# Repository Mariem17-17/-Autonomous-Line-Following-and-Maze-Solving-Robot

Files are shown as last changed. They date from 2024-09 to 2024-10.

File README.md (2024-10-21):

# Autonomous Line-Following and Maze-Solving Robot

## Overview

This project is an Arduino-based autonomous robot designed to follow lines and solve mazes using a combination of infrared sensors, an MPU6050 accelerometer/gyroscope, ultrasonic sensors, and motor control. The robot uses Proportional-Integral-Derivative (PID) control to adjust its path and maintain smooth navigation while avoiding obstacles.

## Hardware Components

- **Arduino** (any compatible model)
- **MPU6050** (Accelerometer and Gyroscope)
- **Infrared Sensors** (IR for line detection)
- **Ultrasonic Sensor** (for obstacle detection)
- **DC Motors** (for movement)
- **LED** (for calibration indication)
- **Limit Switches** (for course control)
- **Power Supply and Wiring**

## Features

### 1. **Line Following**
The robot uses five infrared sensors to distinguish between black (line) and white (background) surfaces. During setup, these sensors are calibrated to detect threshold values for accurate line following.

### 2. **Maze Solving**
The robot utilizes a simple maze-solving algorithm, making decisions based on IR sensor data and ultrasonic sensor feedback to adjust its path through the maze.

### 3. **PID Control**
The MPU6050 provides accurate angle measurements, and a PID control system ensures the robot follows a straight path, even if it starts off misaligned.

### 4. **Obstacle Detection**
The ultrasonic sensor constantly measures distances to obstacles. When an object is detected too close, the robot adjusts its course or stops to avoid collisions.

## How It Works

1. **Sensor Calibration**: The robot calibrates its infrared sensors to differentiate between the black line and the white surface, storing the threshold values for optimal navigation.
  
2. **Line Following**: Using sensor data, the robot adjusts motor speeds to follow the line accurately. Different motor speeds ensure smooth turns and direction changes.

3. **Maze Navigation**: Upon entering a maze, the robot switches modes and begins solving the maze using its sensors to make decisions at each turn or intersection.

4. **Obstacle Avoidance**: The ultrasonic sensor ensures the robot avoids obstacles by measuring the distance to any objects in its path, prompting it to stop or reroute.

## Code Breakdown

- **Infrared Sensors**: Used to calibrate and detect line positions.
- **Motors**: Control the movement and turning of the robot.
- **Ultrasonic Sensor**: Used for obstacle detection and avoidance.
- **PID Control**: Maintains the robot’s direction and speed using data from the MPU6050.
- **Limit Switches**: Detect when the robot reaches the end of the course or a boundary.

## Setup Instructions

1. **Install Required Libraries**:
   - Ensure you have the `Wire.h` and `MPU6050_light.h` libraries installed in your Arduino IDE.
  
2. **Wiring**:
   - Connect the motors, IR sensors, MPU6050, and ultrasonic sensors as per the wiring diagram in the code. Ensure all components have proper power connections.
   
3. **Upload the Code**:
   - Upload the provided Arduino code to the robot.

## Calibration Process

1. Turn on the robot, which will enter the calibration phase with an LED indicator.
2. The robot will automatically calibrate the infrared sensors by scanning the black and white surfaces.
3. After calibration, the robot will begin line-following mode and can be placed on the track or maze.

## PID Tuning

The PID control constant `kp` can be adjusted to improve movement performance. A higher value results in quicker responses to misalignment, while a lower value produces smoother but slower corrections.

## Key Functions

- **seuilblack()** and **seuilwhite()**: Calculate the threshold values for black and white surfaces using the IR sensors.
- **forward_maze()**, **right_turn()**, **left_turn()**: Control robot movement while navigating the maze.
- **dour_pid()**: Adjusts the robot’s heading based on current angle readings from the MPU6050.
- **maze()**: The main maze-solving logic, adjusting movement based on sensor data.

## Usage

Once powered on, place the robot on a track or maze. The robot will autonomously follow the line, and upon detecting a maze, it will switch to maze-solving mode. The ultrasonic sensor ensures obstacle avoidance.

## Future Improvements

- **Dynamic Speed Optimization**: Adjusting speed based on track complexity.
- **Enhanced Maze Solving**: Implementing more advanced algorithms for complex mazes.
- **Improved Obstacle Avoidance**: Developing a more robust system for collision avoidance.

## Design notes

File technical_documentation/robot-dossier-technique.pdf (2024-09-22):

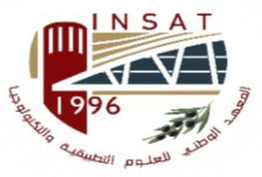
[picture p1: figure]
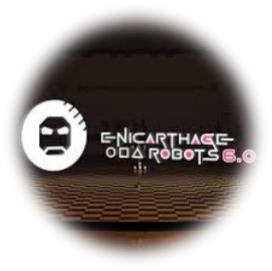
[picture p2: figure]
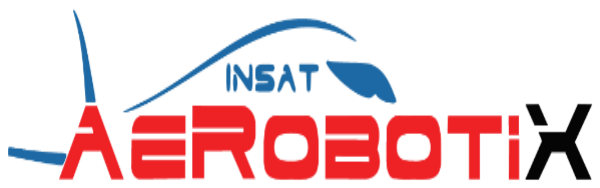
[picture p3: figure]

DOSSIER TECHNIQUE DU ROBOT

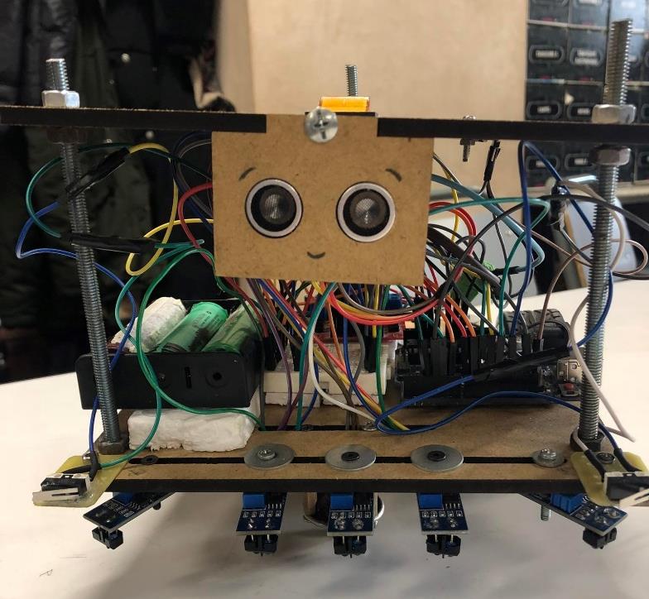
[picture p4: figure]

Réalisé Par :

-Ben Mehrez Mariem

-Guedidi Melek

-Hammami Nada

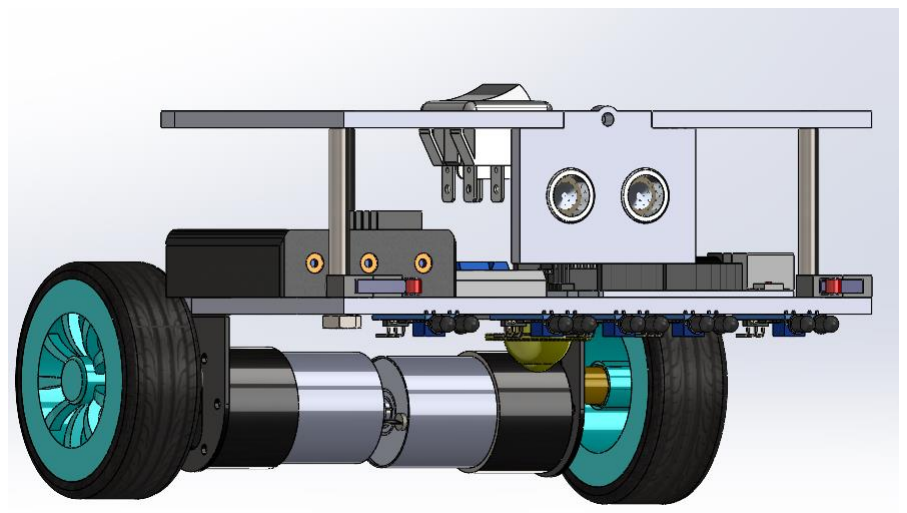
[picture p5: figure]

## Sommaire :

I. Présentation du club
II. | Présentation du robot
| a)Principe de fonctionnement
b) Conception mécanique
| c)Conception Electronique
d) Matériels
e) Conception d’une carte de puissance :

### I. Présentation du Club :

Notre club est leader dans le domaine de la robotique et de l’aéronautique en Tunisie, et représente le pole robotique et aéronautique de l’INSAT. AEROBOTIX est une famille renfermant plus de 150 membres. Nous cherchons à rendre chaque rencontre enrichissante d’un point de vue humain et technologique .Chaque membre apporte de l’énergie aux autres, nous nous attachons à insuffler cette énergie pour innover et concrétiser nos projets qui feront objets des compétitions et des expositions nationales et internationales. Nous offrons une excellente formation pour nos membres et nous garantissons une expérience innovante, exceptionnelle et collaborative. Notre club est le club le plus performant à l’INSAT avec plus de 100 participations à des compétitions nationales, 17 participations à l’échelle internationale et remportant ainsi plusieurs prix, plus que 35 médailles et 25 trophées.

### II. Présentation du robot :

a) Principe du fonctionnement :

Dans ce jeu, les robots tentent de suivre et survivre aux rebondissements physiques des jeux SQUID GAME. Le compétiteur doit suivre le bon chemin, schématisé sur la maquette par le mot [SQUID GAME]. Il est appelé à résoudre le maze du lettre M ainsi que continuer son chemin sur la partie de maquette de couleurs inversées et célébrer sa victoire.

b) Conception mécanique :

Il s’agit d’un assemblage virtuel des principales pièces de notre robot. Cette conception 3D nous permettra de :

| • Assurer les bonnes dimensions de totalité des pièces.

- Imprimer sur papier les dimensions réelles des pièces une par une, ce qui va nous faciliter leur fabrication.
- Avoir une idée virtuelle de notre projet.

Et pour cette raison qu’on a utilisé le logiciel de conception
3D « SOLIDWOKS »

✓ ASSEMBLAGE DU ROBOT
- Vue de face :

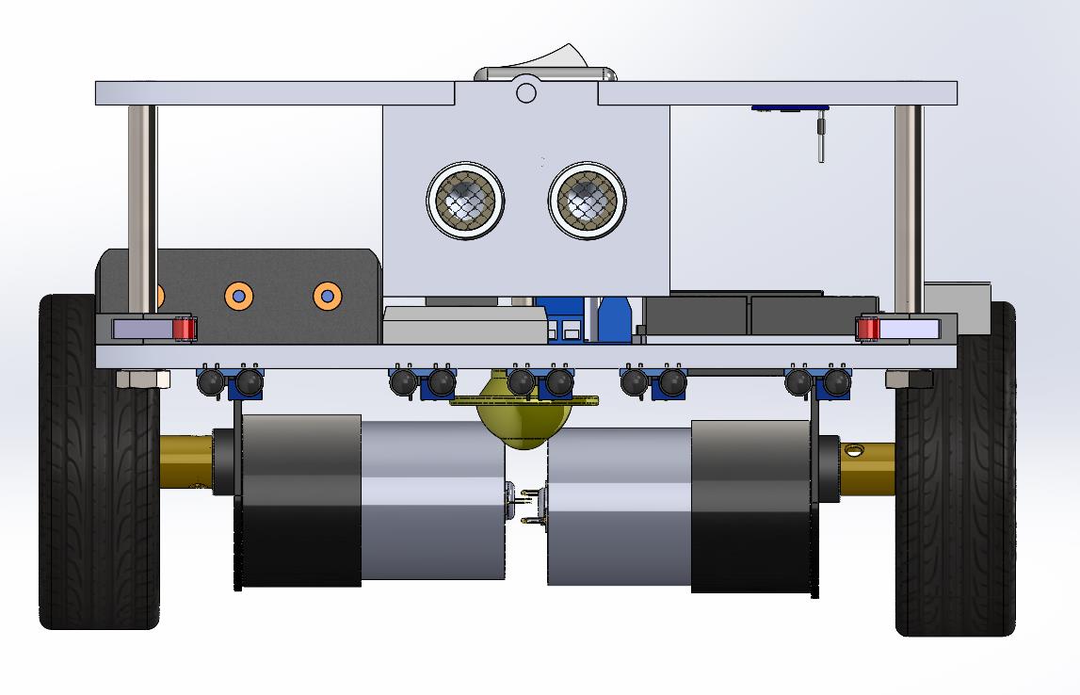
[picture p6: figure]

- Vue de Dessous :

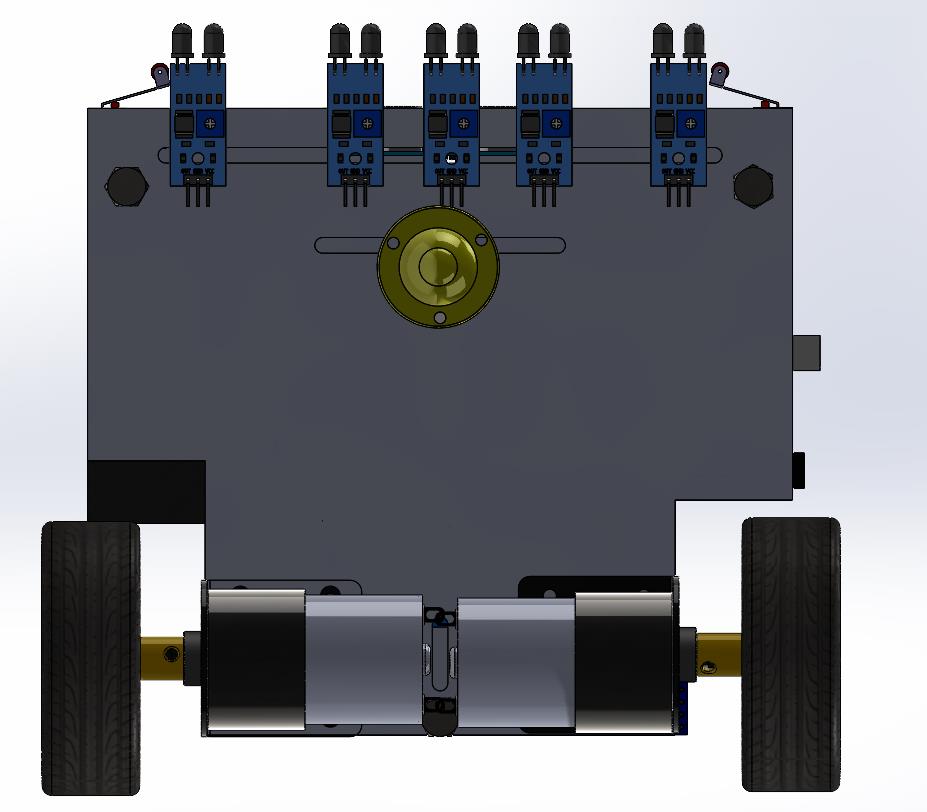
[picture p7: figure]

- Vue de Dessus :

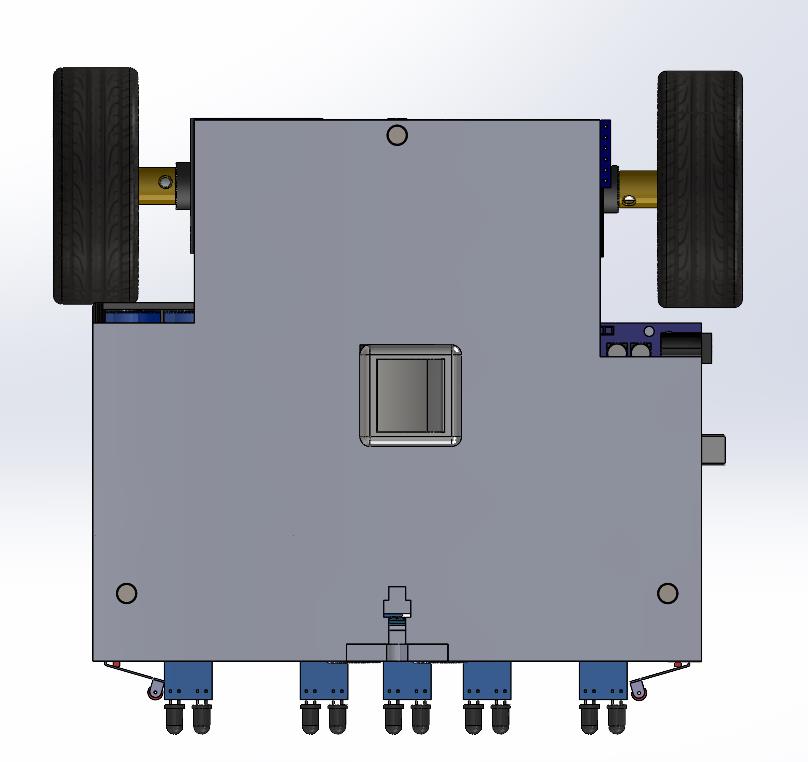
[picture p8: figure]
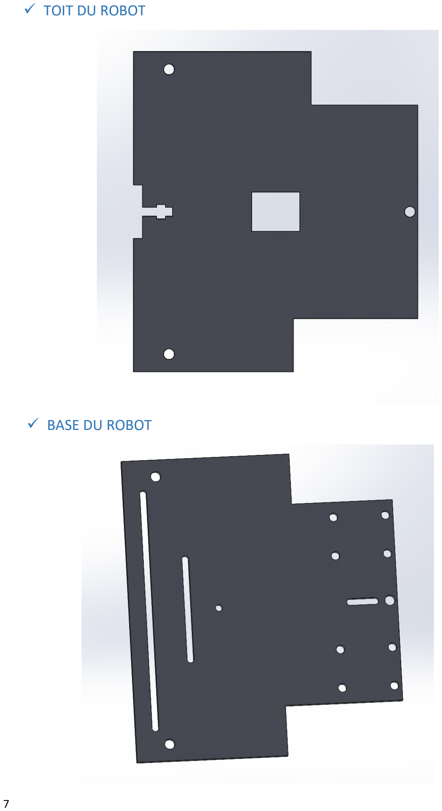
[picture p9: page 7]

✓ TOIT DU ROBOT

✓ BASE DU ROBOT

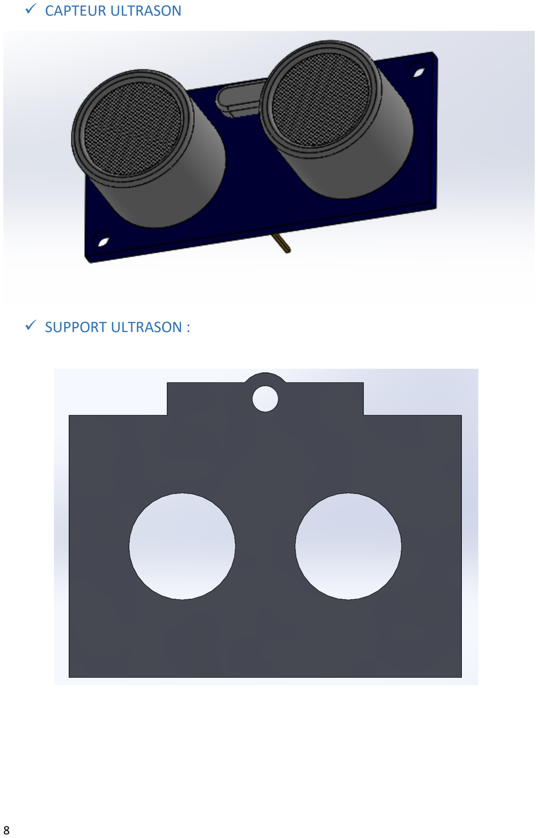
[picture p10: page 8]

✓ CAPTEUR ULTRASON

✓ SUPPORT ULTRASON :

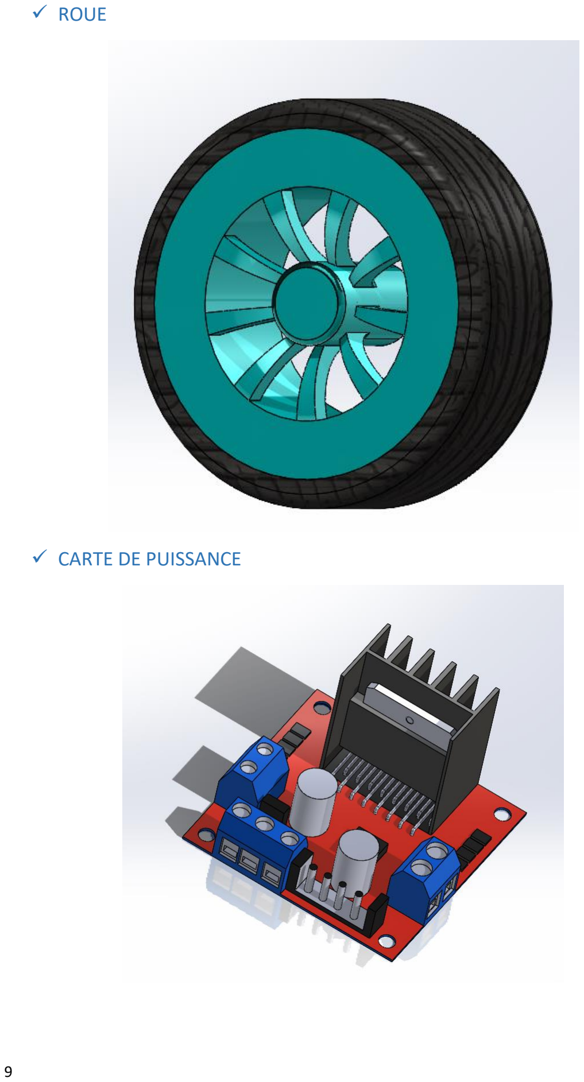
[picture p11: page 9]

✓ ROUE

✓ CARTE DE PUISSANCE

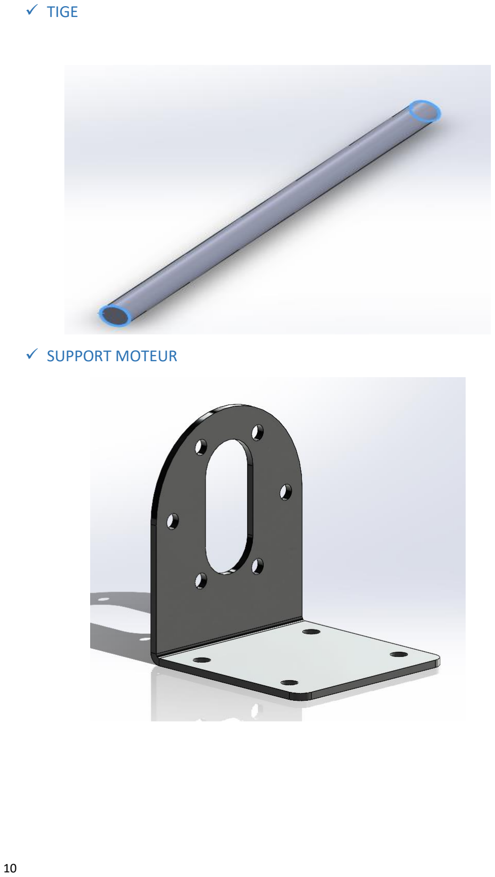
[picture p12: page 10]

✓ TIGE

✓ SUPPORT MOTEUR

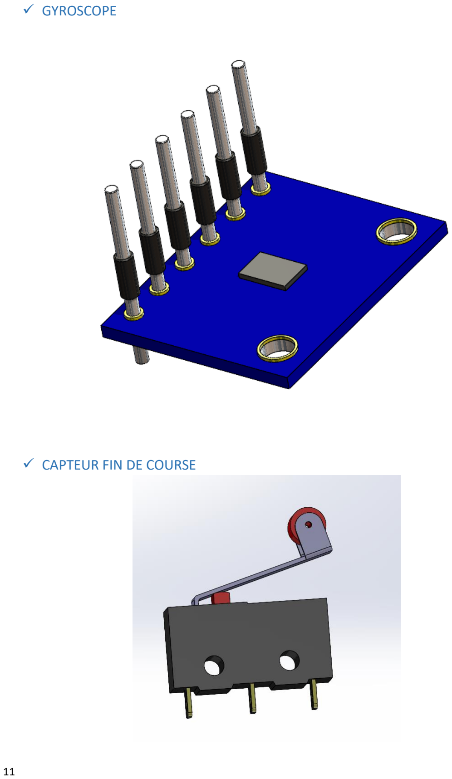
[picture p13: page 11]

✓ GYROSCOPE

✓ CAPTEUR FIN DE COURSE

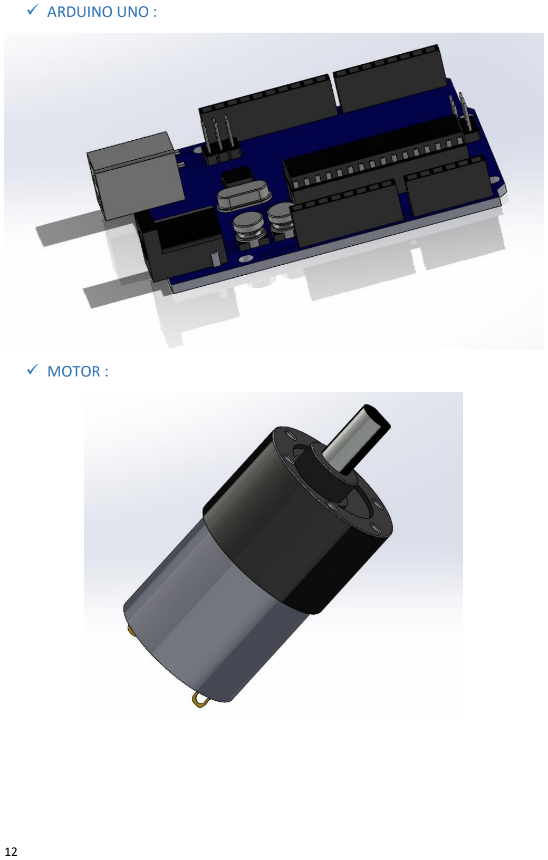
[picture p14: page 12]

✓ ARDUINO UNO :

✓ MOTOR :

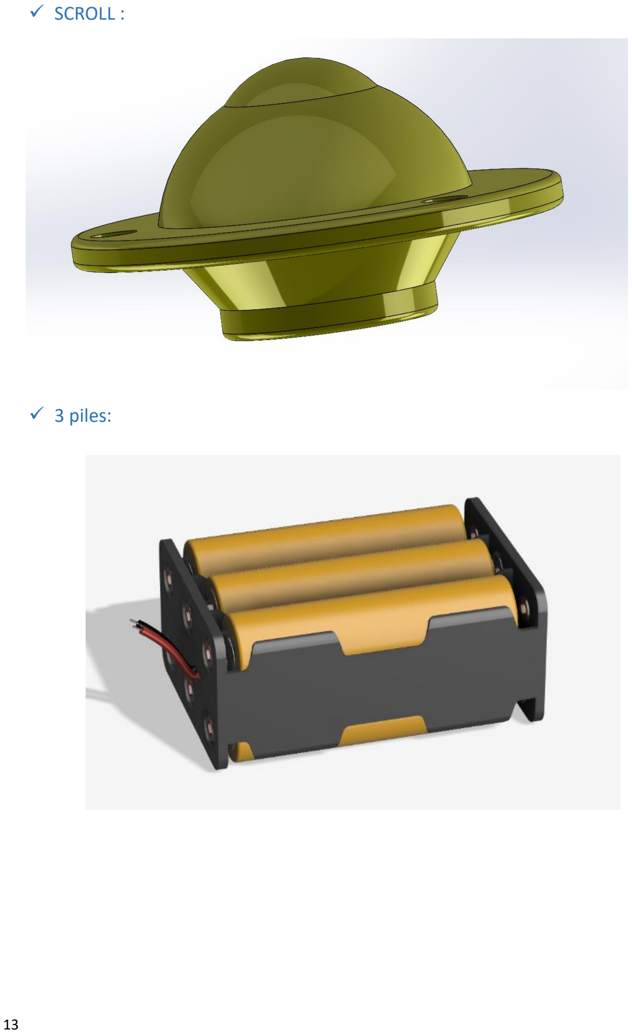
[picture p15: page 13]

✓ SCROLL :

✓ 3 piles:

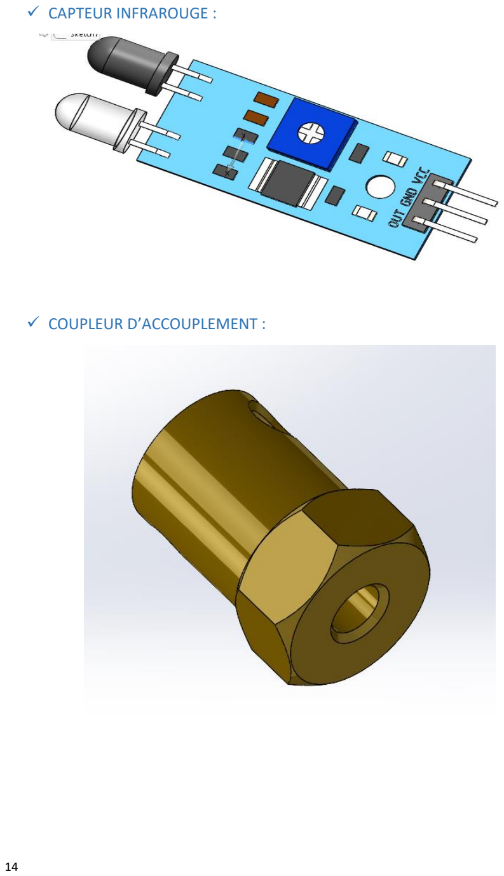
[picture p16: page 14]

✓ CAPTEUR INFRAROUGE :

✓ COUPLEUR D’ACCOUPLEMENT :

c) Conception électronique :

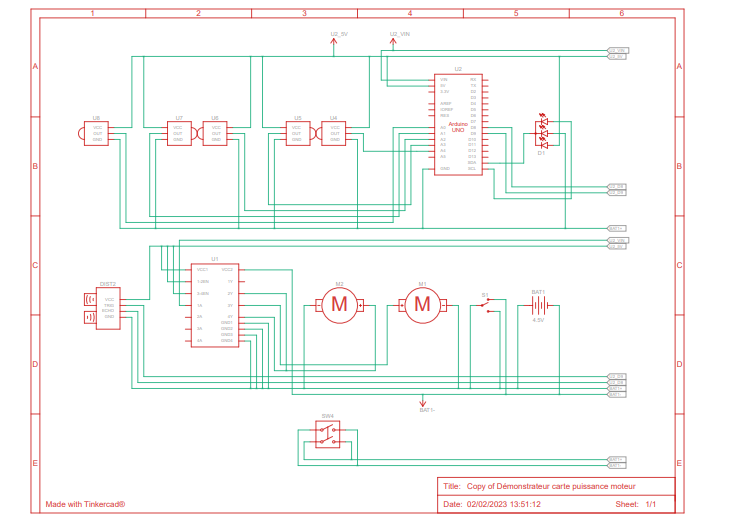
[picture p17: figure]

d) Matériels :
Quantité | Désignation
Partie Mécanique | 2 | Moteur
| 2 | Roue
| 1 | Scroller
| 1 | Bouton Marche/arrêt
| 2 | Coupleur d’accouplement
| 3 | Pile
Partie Electronique | 1 | Carte puissance
| 5 | Capteur Infrarouge
| 1 | Capteur Ultrason
| 1 | Gyroscope
| 2 | Capteur fin de course
Partie Programmation | 1 | Microcontrôleur (ARDUINO UNO)
e) Conception d’une carte de puissance :

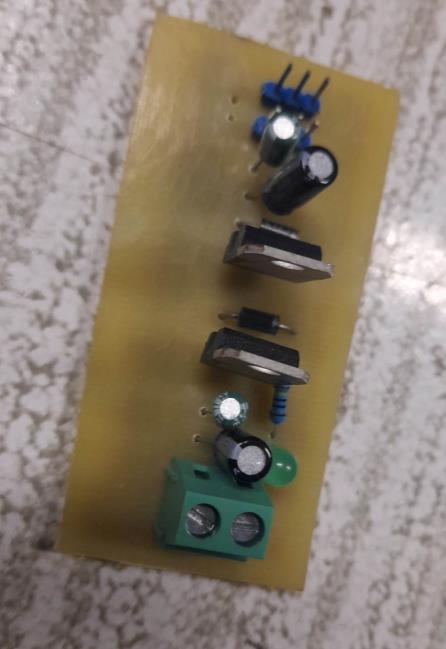
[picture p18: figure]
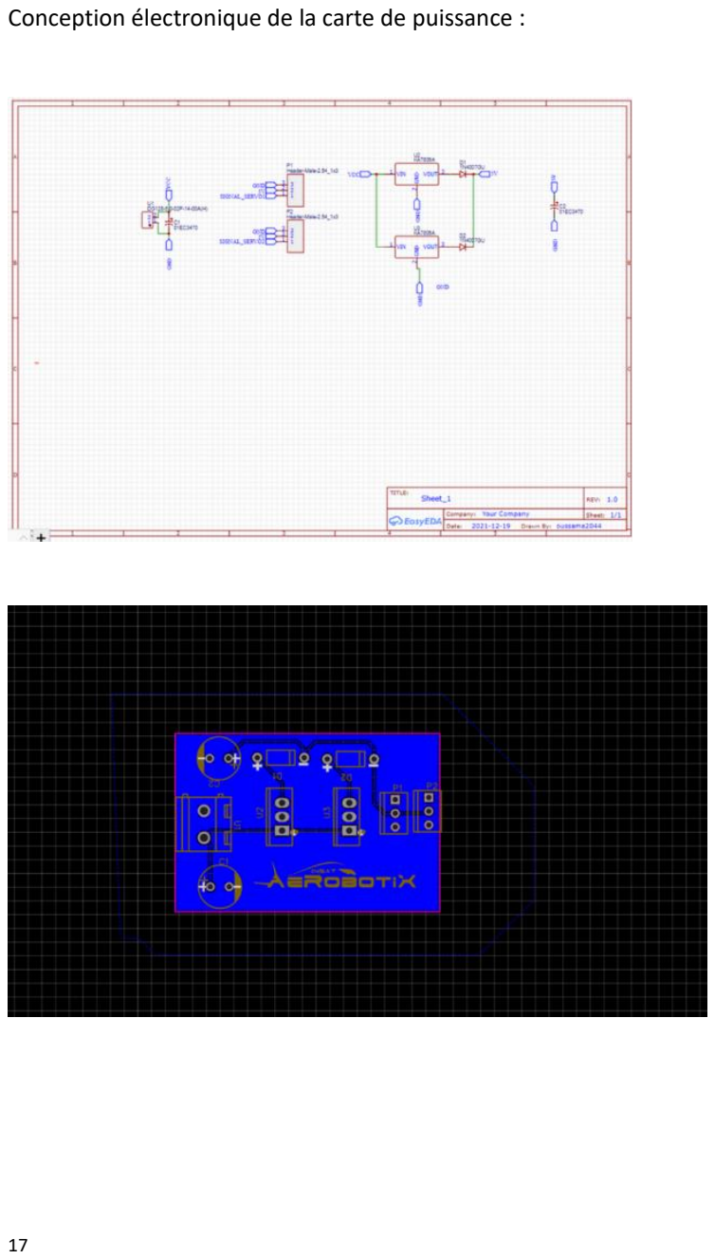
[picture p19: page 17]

Conception électronique de la carte de puissance :

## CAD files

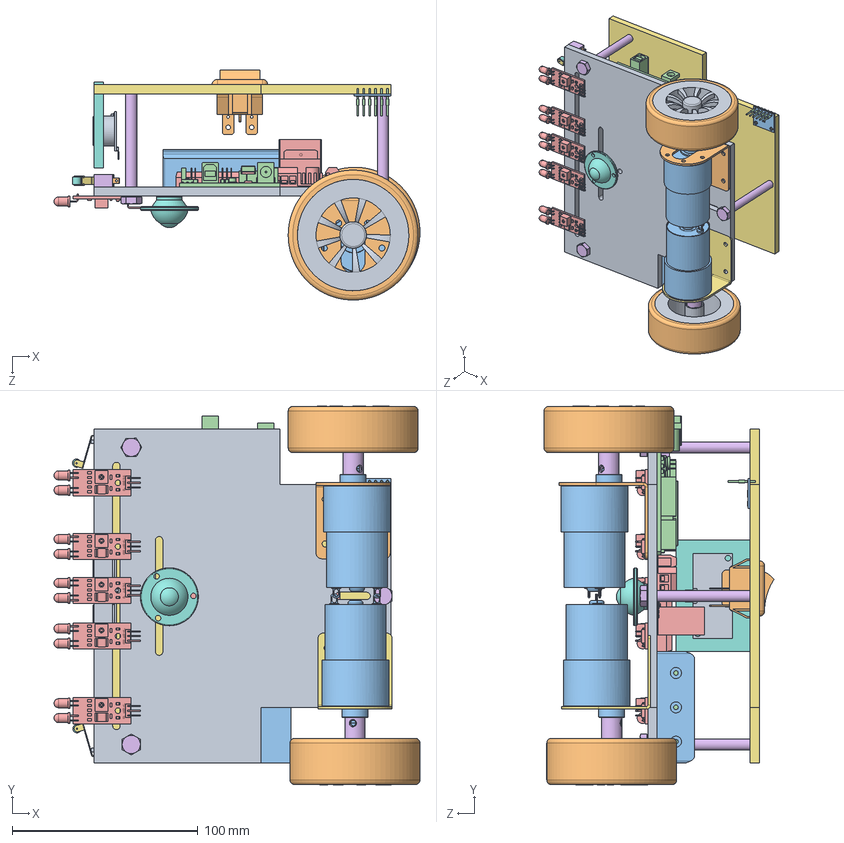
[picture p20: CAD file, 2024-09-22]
mechanical_design/final_assembly.SLDASM
197.1 x 204.0 x 123.9 mm
GDOURAbas
37 mm DC Geared Motor Mounting Bracket
motor x 2
Arduino Uno R3
Motor Driver
6mmID_18mmL_hex_adapter.stp x 2
37 mm DC Geared Motor Mounting Bracket (1)
scroll
wheel2 x 2
contour-wheel x 2
pin
battery_base x 3
Electronics_Prototyping_Breadboard_35x45x8_17x10holes
hexagon head bolts-full thread gb x 3
GDOURAhaut
TEST1SUPPORT
HC-SR04 Ultrasonic sensor
Switch JS618.stp
Gyroscope sensor
Gyroscope sensor straight lead x 6
Sensor, IR, Arduino Type, Flying Fish MH-B x 5
corp x 2
support Roulette x 2
Roulette x 2
Poussoir x 2
Patte x 6

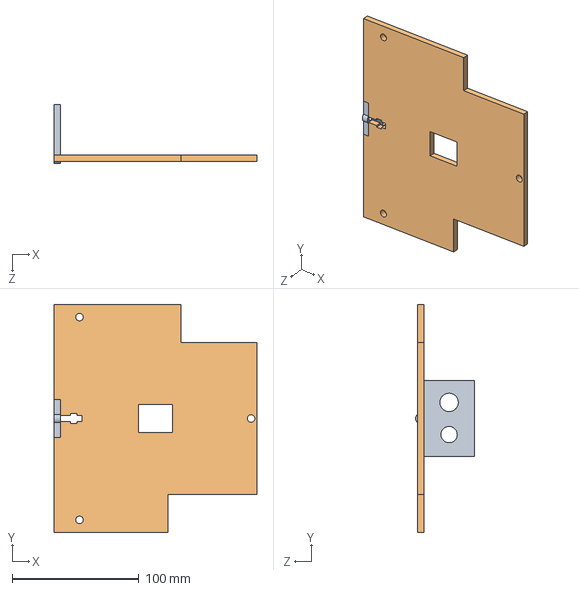
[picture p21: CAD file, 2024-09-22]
mechanical_design/Baseh_supp.SLDASM
160.0 x 180.0 x 46.5 mm
TEST1SUPPORT
GDOURAhaut

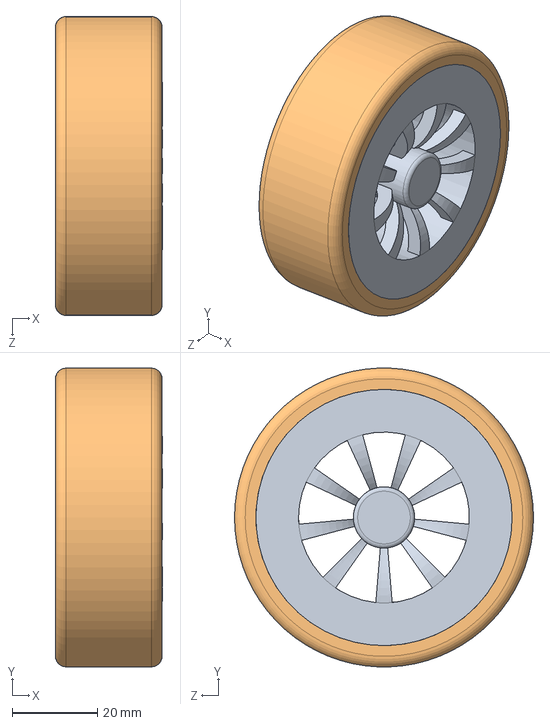
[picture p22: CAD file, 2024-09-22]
mechanical_design/AssemblageWheel.SLDASM
25.1 x 69.9 x 70.0 mm
wheel2
contour-wheel

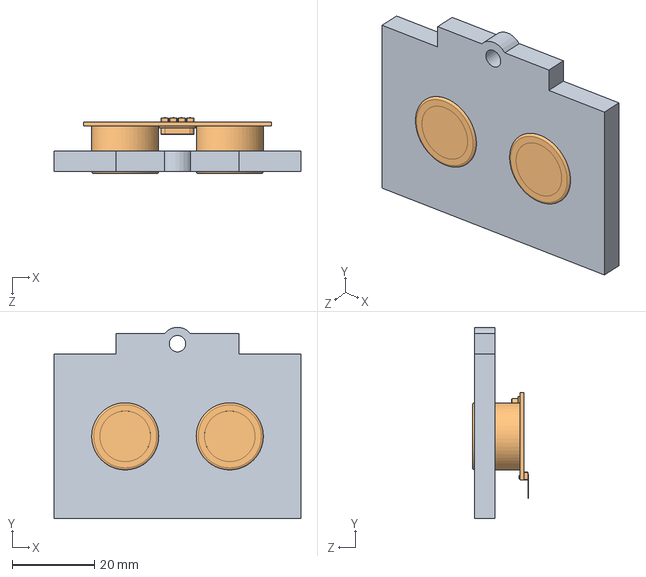
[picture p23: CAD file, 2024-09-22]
mechanical_design/AssemblageUltraSon.SLDASM
60.0 x 46.5 x 13.6 mm
TEST1SUPPORT
HC-SR04 Ultrasonic sensor

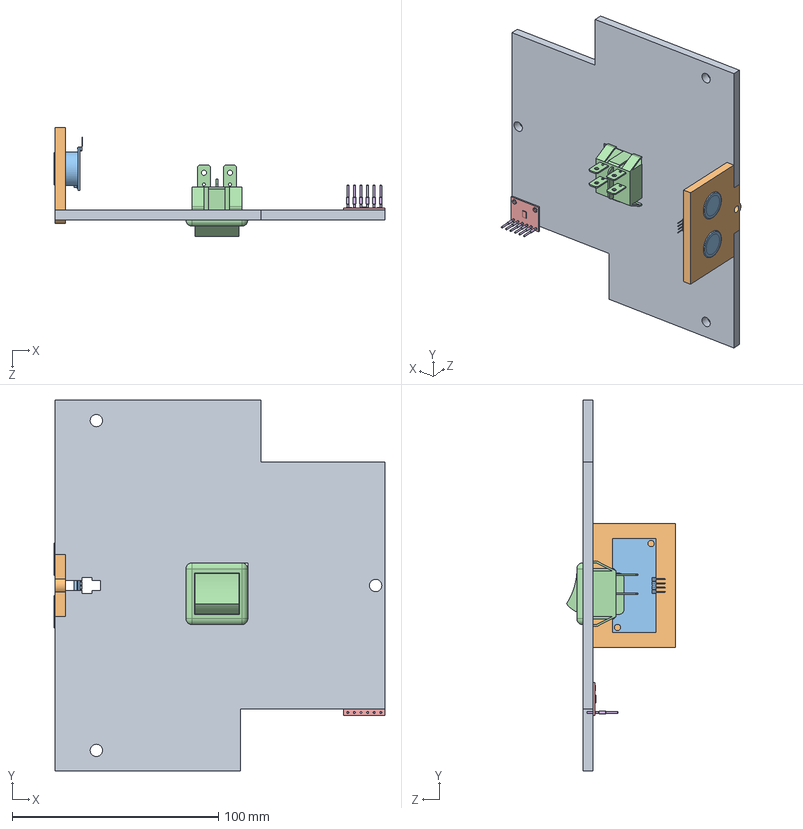
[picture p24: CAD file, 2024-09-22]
mechanical_design/AssemblageBaseHaute.SLDASM
160.5 x 180.0 x 52.9 mm
GDOURAhaut
TEST1SUPPORT
HC-SR04 Ultrasonic sensor
Switch JS618.stp
Gyroscope sensor
Gyroscope sensor straight lead x 6

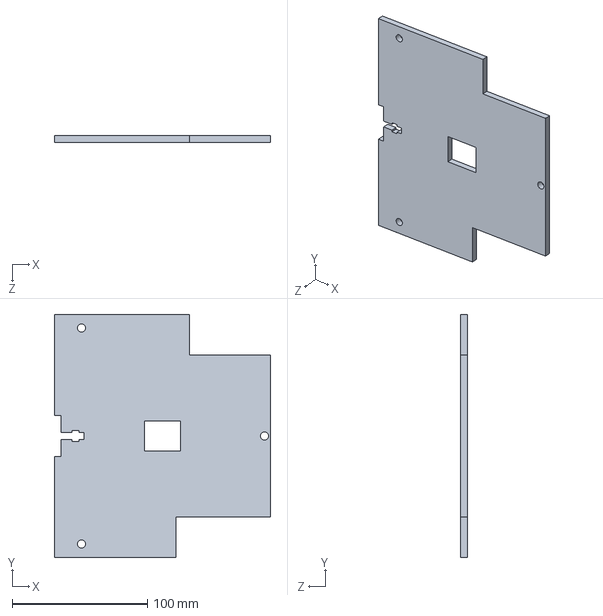
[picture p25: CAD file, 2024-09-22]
mechanical_design/Assemblage2.SLDASM
160.0 x 180.0 x 5.00 mm

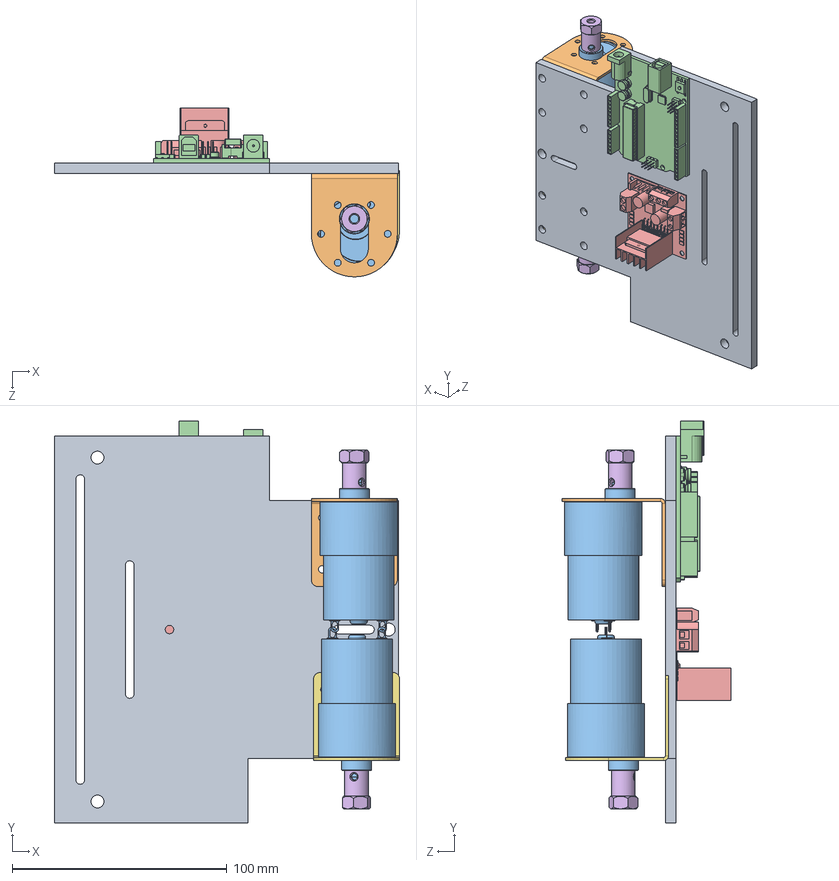
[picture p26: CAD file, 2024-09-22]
mechanical_design/Assemblage1-2.SLDASM
160.5 x 187.0 x 78.5 mm
GDOURAbas
37 mm DC Geared Motor Mounting Bracket
motor x 2
Arduino Uno R3
Motor Driver
6mmID_18mmL_hex_adapter.stp x 2
37 mm DC Geared Motor Mounting Bracket (1)

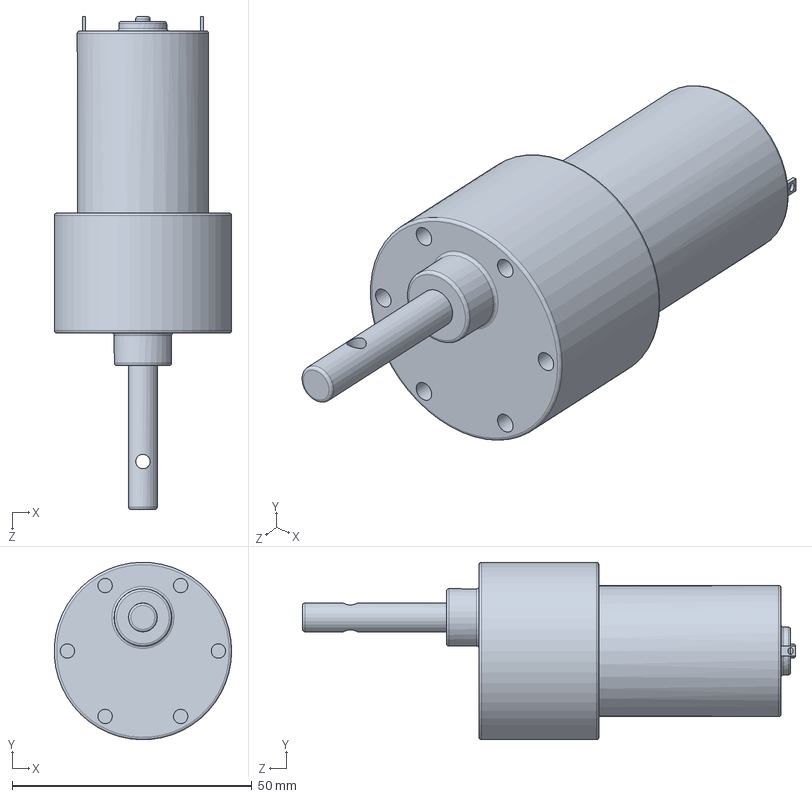
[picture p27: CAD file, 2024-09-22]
mechanical_design/moteur + réducteur.SLDPRT
37.0 x 37.0 x 102.8 mm

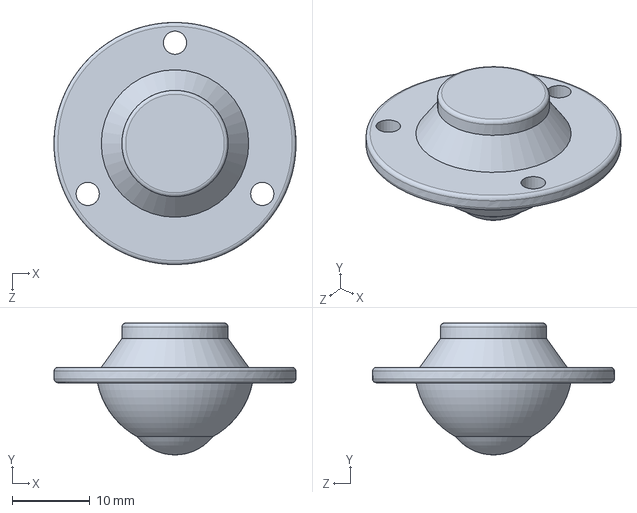
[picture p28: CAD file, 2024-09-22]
mechanical_design/scroll.SLDPRT
31.2 x 17.0 x 31.2 mm

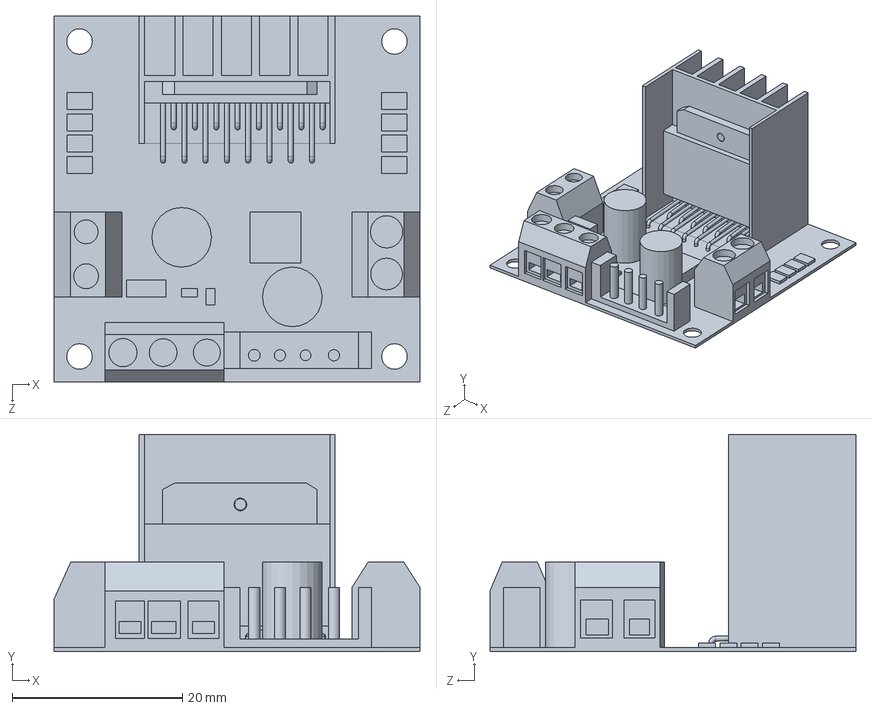
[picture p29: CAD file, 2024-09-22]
mechanical_design/Motor Driver.SLDPRT
43.0 x 25.5 x 43.0 mm

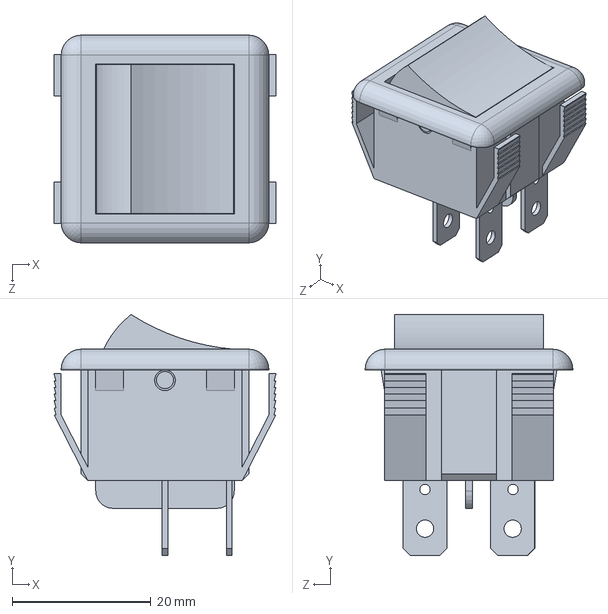
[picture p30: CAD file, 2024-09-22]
mechanical_design/Switch JS618.stp.SLDPRT
32.0 x 34.8 x 30.0 mm

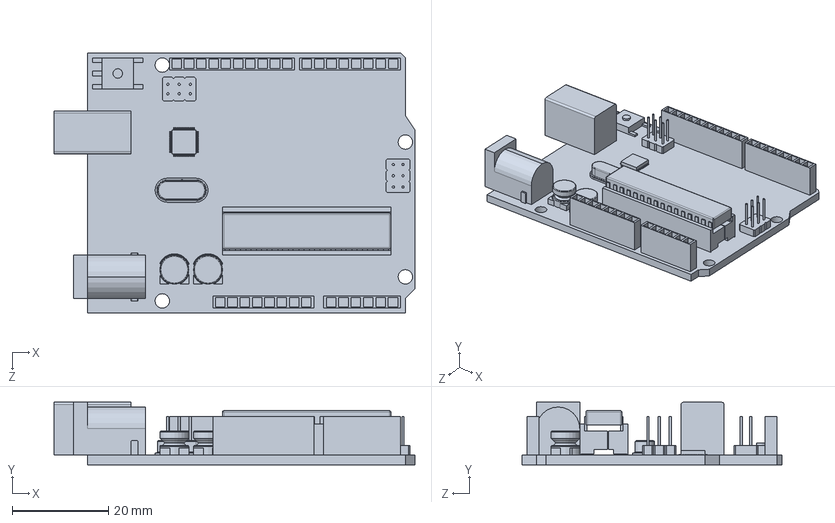
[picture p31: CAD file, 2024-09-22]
mechanical_design/Arduino Uno R3.SLDPRT
75.0 x 13.0 x 54.0 mm

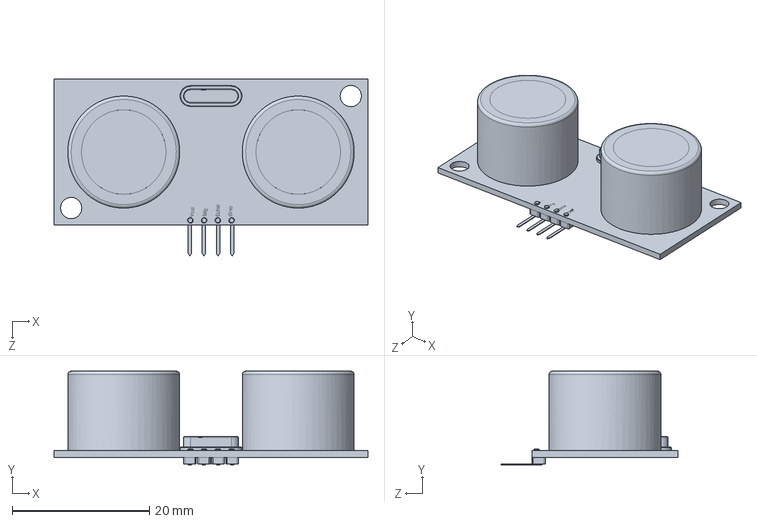
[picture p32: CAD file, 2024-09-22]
mechanical_design/HC-SR04 Ultrasonic sensor.SLDPRT
45.7 x 13.6 x 25.8 mm

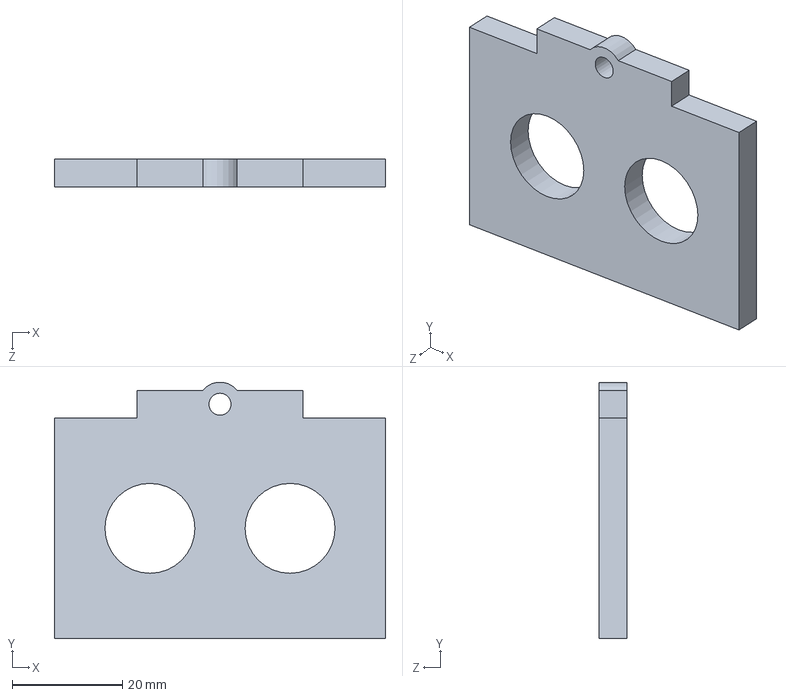
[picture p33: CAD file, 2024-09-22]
mechanical_design/TEST1SUPPORT.SLDPRT
60.0 x 46.5 x 5.00 mm

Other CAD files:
mechanical_design/Assemblage.SLDASM

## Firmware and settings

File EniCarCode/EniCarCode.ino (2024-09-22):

#include "Wire.h"
#include <MPU6050_light.h>

//---------------------------Seuil Colors--------------------
int seuilGG;
int seuilG;
int seuilC;
int seuilD;
//int seuilDD;

//----------------------------memory---------------------------
int past;
int counterpast = 0;

int counterwhite = 0;

int vitessemax = 200; //nprmalement 200!!!!!!!!!!!!!!!!!!!!!!!!
// ---------------------------pid-----------------------------
float kp = 3;

//---------------------------geo----------------------------
MPU6050 mpu(Wire);
unsigned long timer = 0;
float new_angl = 0;

// ---------------------------ultrason--------------------------

int trig = 9;
int echo = 8;

// ---------------------------fin de course--------------------------

int finCourseR = 3;
int finCourseL = 4;

float duration_us, distance_cm;

//---------------------------motors------------------------------
//left motor
int in1 = 5;
int in2 = 6;
//right motor
int in3 = 10;
int in4 = 11;

//---------------------------infrarouge-------------------------

int if_gg= A0;
int if_g = A1;
int if_c = A2;
int if_d = A3;
int if_dd= 12;

//---------------------------led---------------------------
int led = 13;


//---------------------------calcul val black----------------------

float seuilblack(int pin_sensor){
  float seuilblack = 0;
  for (int i=0; i < 50; i++)
  {
    seuilblack += analogRead(pin_sensor);
  }
  return seuilblack = seuilblack / 50;
}

//------------------------calcul val white-------------------------

float seuilwhite(int pin_sensor){
  float seuilwhite = 0;
  for (int i=0; i < 50; i++)
  {
    seuilwhite += analogRead(pin_sensor);
  }
  return seuilwhite = seuilwhite / 50;
}




//------------------------setup------------------------
void setup() {
  Serial.begin (9600);

  // set up the imu---------------------------

  Serial.print(F("MPU6050 status: "));
  Wire.begin();
  byte status = mpu.begin();
 
  Serial.println(status);
  while(status!=0){ }
  Serial.println(F("Calculating offsets, do not move MPU6050"));
  mpu.calcOffsets(); // gyro and accelero
  Serial.println("Done!\n");  

  // configure the fin de course pins----------
  pinMode(finCourseR, INPUT_PULLUP);
  pinMode(finCourseL, INPUT_PULLUP);   

  // configure the ultrason pins----------
  pinMode(trig, OUTPUT);
  pinMode(echo, INPUT);

  // configure the motor pins-------------
  pinMode(in1, OUTPUT);
  pinMode(in2, OUTPUT);
  pinMode(in3, OUTPUT);
  pinMode(in4, OUTPUT); 


  pinMode(led, OUTPUT);
  
  // configure infrarouge pins---------------
  pinMode(if_gg,INPUT);
  pinMode(if_g, INPUT);
  pinMode(if_c, INPUT);
  pinMode(if_d, INPUT);
  pinMode(if_dd,INPUT);

  //calibrage colors-------------------------

  //seuilBlack-------------------------------
  
  digitalWrite(led, HIGH);
  delay(3000);
  float SBgg = seuilblack(if_gg);
  float SBg = seuilblack(if_g);
  float SBc = seuilblack(if_c);
  float SBd = seuilblack(if_d);
  //float SBdd= seuilblack(if_dd);
  digitalWrite(led, LOW);
  delay(2000);

  //seuilWhite--------------------------------
  
  digitalWrite(led, HIGH);
  delay(3000);
  float SWgg = seuilwhite(if_gg);
  float SWg = seuilwhite(if_g);
  float SWc = seuilwhite(if_c);
  float SWd = seuilwhite(if_d);
  //float SWdd = seuilwhite(if_dd);
  digitalWrite(led, LOW);
  
  //calcul seuil--------------------------------

  seuilGG= (SBgg + SWgg)/2;
  seuilG = (SBg  + SWg )/2;
  seuilC = (SBc  + SWc )/2;
  seuilD = (SBd  + SWd )/2;  
  //seuilDD= (SBdd + SWdd)/2;

  /*test
  Serial.println("seuilGG start");
  Serial.println(seuilGG);
  Serial.println(seuilG);
  Serial.println(seuilC);
  Serial.println(seuilD);
  //Serial.println(seuilDD);
  Serial.println("seuilGG end");
  /*test*/
  
  /*test
  //Serial.println(seuilblack(if_dd));
  /*test*/

  while( digitalRead(finCourseR) == 0){
    // mata3mel chey
    Serial.println("olala");}

   
}

//----------------------maze-------------------------------------------

//Calcul distance-------------------------
float distance(){
    digitalWrite (trig, HIGH);
    delay(20);
    digitalWrite (trig, LOW);
    float duration=pulseIn(echo,HIGH);
    float distance=(duration/2)/29.1;
    return distance;
  }

//right turn in maze----------------
void right_turn() {
    //leftmotor
    analogWrite(in1,0);
    analogWrite(in2,70);

   //rightmotor
    analogWrite(in3,(70));
    analogWrite(in4,0);
 }

// left turn in maze-----------------------
void left_turn() {
  //leftmotor
   analogWrite(in1,(70));
   analogWrite(in2,0);

  //rightmotor
   analogWrite(in3,0);
   analogWrite(in4,70);
 }

// forward maze---------------------------------
void forward_maze(){
  //leftmotor
   analogWrite(in1,0);
   analogWrite(in2,70);

   //rightmotor
   analogWrite(in3,0);
   analogWrite(in4,70);
}

//forward asservie-------------------------------
void forward_pid(){
  
   //condition init
   mpu.update();
  float angl = (mpu.getAngleZ());

  while(true){
    mpu.update();
    float err = mpu.getAngleZ() - angl;
    float v_right = vitessemax+err*kp;
    float v_left  = vitessemax-err*kp;
    
    if (v_right < 0 ){
      v_right = 0;
    } else if 
      (v_right > 255 ){
      v_right = 255;
    }

    if (v_left < 0 ){
        v_left = 0;
    } else if 
      (v_left > 255 ){
       v_left = 255;
    }

    analogWrite(in1,0);
    analogWrite(in2,v_left);

    analogWrite(in3,0);
    analogWrite(in4,v_right);

    if ( digitalRead(finCourseR) && digitalRead(finCourseL) )
    {break;}
  }
}

//----------------inverse chaine-----------------------
String inverse_chaine(String ch){
  int lengthch = ch.length();
  for (int i = 0; i < lengthch; i++){
    if (ch[i] == '0'){
      ch[i] = '1';
    }
    else {ch[i] = '0';}
  }
  return ch;
}

void arrete(){
  analogWrite(in1,0);
  analogWrite(in2,0);

  analogWrite(in3,0);
  analogWrite(in4,0);
}

void wakher(){

  analogWrite(in1,100);
  analogWrite(in2,0);

  analogWrite(in3,100);
  analogWrite(in4,0);

   delay(500);
  
  while (distance < 10){
  analogWrite(in1,100);
  analogWrite(in2,0);

  analogWrite(in3,100);
  analogWrite(in4,0);
  }
  arrete();
  
}

void dour_pid(float target_angl){
  //condition init
   ;
   float angl = target_angl + new_angl;

  while(true){
    mpu.update();
    float err = mpu.getAngleZ() - angl;

    if (err > 1){
      left_turn();}
      else if(err < -1){
        right_turn();
      }
      else {
        arrete();

      break;}
      
  }
}
//--------------------maze-----------
void maze(float target_angl){
  
  forward_pid();
  arrete();
  forward_maze();
  delay(500);
  mpu.update();
  new_angl = mpu.getAngleZ();
  wakher();
  
  dour_pid(target_angl);
  
}

//------------------------------------------------
void forward() {
  //
  analogWrite(in1,0);
  analogWrite(in2,vitessemax);

  analogWrite(in3,0);
  analogWrite(in4,vitessemax);
}

void backward(){
  analogWrite(in1,vitessemax);
  analogWrite(in2,0);

  analogWrite(in3,vitessemax);
  analogWrite(in4,0);
}

void right() {
  //leftmotor
  analogWrite(in1,0);
  analogWrite(in2,vitessemax);

  //rightmotor
  analogWrite(in3,vitessemax*0.5);
  analogWrite(in4,0);
 }

void left() {
  //leftmotor
  analogWrite(in1,vitessemax*0.5);
  analogWrite(in2,0);

  //rightmotor
  analogWrite(in3,0);
  analogWrite(in4,vitessemax);
 }
 
String readSensors()
 {
  String ch="";
  
  //IR GAUCHE EXTREME------------------------------------------
    if ( analogRead(if_gg)<seuilGG){
      ch=ch+'0';}
      else {
        ch=ch+'1';}
    
  //IR GAUCHE-------------------------------------------------
    if ( analogRead(if_g)<seuilG)
    {
      ch=ch+'0';}
        else {
    ch=ch+'1';}
    
  //IR CENTER-------------------------------------------------------
     if ( analogRead(if_c)<seuilC){
      ch=ch+'0';}
      else {
        ch=ch+'1';}
    
  //IR DROITE-------------------------------------------------------
     if ( analogRead(if_d)<seuilD)
     {
      ch=ch+'0';}
       else {
        ch=ch+'1';}
 

  //IR DROITE EXTREME------------------------------------------------
    if (digitalRead(if_dd))
    {
      ch=ch+'1';}
      else {
        ch=ch+'0';}
        return ch;}

///-----------------------------loop------------
void loop() {

//------------------Logique blanc-------------------------------

if (analogRead(if_gg) > seuilGG)
{ past = 1;
counterpast = 0;
  }

if (digitalRead(if_dd))
{ past = 0;
counterpast = 0;
  }

String chaine= readSensors();
Serial.println(chaine);
if (chaine == "00100"){
  counterpast++;
}


if (counterpast>40){
  past = 3;
  counterpast = 0;
}

 /*forward-------------------------------------------------*/
 
 if ( chaine=="00100" /*or chaine=="10010" */
 or chaine=="01010" 
 /*or chaine=="10110" */or chaine=="01110" or chaine=="10001" or chaine=="01001"/* 
 or chaine=="11001" */or chaine=="10101" /*or chaine=="01101" */
 /*or chaine=="10011" or chaine=="01011" or chaine=="11011" */ /*zedna 10111 01001 bch me yerja3ch lel lowel*/
 or chaine=="10111" or chaine=="11111" or chaine=="10100" or chaine=="11010" or  chaine=="11110"  or chaine=="01111" 
 )
 /*11010 zedneha ll forward*/
 {forward();}
 
 /*left-------------------------------------------------*/
 else if (chaine=="10000" or chaine=="01000" or chaine=="11000" or 
  /*or chaine=="10100"  hattineha forward*/chaine=="01100" or chaine=="11100"
  
   /*or chaine=="11101"*/) 
 {
// if ( past == 3 ){
    left();
    
//  }
//  else if (past == 1){
//    forward();
//  }
//  else{
//    left();}
  }
  

/*right-------------------------------------------------*/
 else if (chaine=="00110" or chaine=="00001" or chaine=="00011" or chaine=="00111"
 or chaine=="00101" or chaine=="00010" ) 
 {
 right();
  } 
  else if (chaine=="00000" ){
    if (past == 1){
      left();
    }
    else if (past == 0)
    {
      right();
    }
  else if (past == 3){
    forward();
  }
  }

  if ( digitalRead(finCourseR)  && digitalRead(finCourseL) ){
     maze(86);
      maze(-86);
      maze(-86);
      maze(86);
      maze(86);
      maze(-86);
      maze(-86);
      maze(86);
      
      chaine = readSensors();

        //------------------Maze to partie noire------------------------
        
      while(!((chaine[0] == '1') && (chaine[4] == '1'))){
        chaine = readSensors();
        forward(); 
      }

       //--------------------Partie noire---------------------
      while(true){
        if (analogRead(if_gg) < seuilGG){ 
          past = 1;
          }

        if (!digitalRead(if_dd)){ 
          past = 0;
          }
          
        String chaine = readSensors();
        chaine = inverse_chaine(chaine);

        if (chaine == "11111"){
          counterwhite++;
        }

        if (counterwhite > 150){
          arrete();
          counterwhite = 0;
          delay(15000);
        }

        Serial.println(inverse_chaine(chaine));
        
        if (chaine == "00100"){
          counterpast++;
          }
          
        if (counterpast>90){
          past = 3;
          counterpast = 0;
          }
 
 
 /*forward-------------------------------------------------*/
 
 if ( chaine=="00100" /*or chaine=="10010" */
 or chaine=="01010" 
 /*or chaine=="10110" */or chaine=="01110" or chaine=="10001" /*or chaine=="01001" 
 or chaine=="11001" */or chaine=="10101" /*or chaine=="01101" */
 /*or chaine=="10011" or chaine=="01011" or chaine=="11011" or chaine=="10111"  */ 
 or chaine=="11111" or
 chaine=="11000" or 
 chaine=="11100" or chaine=="10100" or chaine=="10000"  or chaine=="11010"  )
 {forward();}
 
 /*left-------------------------------------------------*/
 else if ( chaine=="01000" or chaine=="01100" or chaine=="11110" /*or chaine=="11101"*/) 
 {
  left();}
// 
/*right-------------------------------------------------*/
 else if (chaine=="00110" or chaine=="00001" or chaine=="00011" or chaine=="00111"
  or chaine=="01111" or chaine=="00101" or chaine=="00010" ) 
 {
 right();
  } 
  
  else if (chaine=="00000" ){
    
    if (past == 1){
      left();
    }
    else if (past == 0)
    {
      right();
    }
    else if (past == 3){
    forward();
  }
  }
  }

  }
}
 
